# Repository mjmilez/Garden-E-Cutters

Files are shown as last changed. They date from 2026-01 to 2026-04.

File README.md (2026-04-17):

# Garden E-Cutters

## Overview
The Garden E-Cutters shears are a smart harvesting tool that records each cut event along with high-accuracy GPS data. When a cut is detected, the system captures an RTK-corrected GNSS position, logs the event locally, and transmits it to a base station for visualization on a live map dashboard.

## Key Features
- RTK GNSS positioning (u-blox ZED-F9P) for centimeter-level accuracy  
- Hall effect sensor-based cut detection  
- ESP32-based embedded control system  
- Local CSV logging for offline reliability  
- Bluetooth Low Energy (BLE) data transfer to base station  
- Audible and LED feedback for user interaction  
- Debounced trigger logic to prevent duplicate cut events  

## How It Works
1. A cut is detected using a Hall effect sensor on the shears.  
2. The ESP32 captures the next valid GNSS (GNGGA) message from the ZED-F9P.  
3. The event (timestamp + GPS + fix data) is stored locally in a CSV buffer.  
4. When connected, data is transmitted over BLE to the base station.  
5. The base system visualizes cut locations on a map dashboard.

## Hardware
- ESP32 microcontroller  
- u-blox ZED-F9P RTK GNSS receiver  
- Hall effect sensor (cut detection)  
- Piezo buzzer (status feedback)  
- Status LEDs  
- Battery-powered field enclosure  

## Design Focus
- Low-latency cut-to-log workflow  
- Reliable operation under intermittent connectivity  
- Minimal power and compute load on the field device  
- Robust data capture even during GNSS or BLE interruptions  

## Status
Prototype validated in field-like testing with reliable event detection, RTK-level positioning, and stable end-to-end data transfer to the base system.

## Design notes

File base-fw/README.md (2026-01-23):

# Base Firmware

The base firmware runs on an ESP32 (ESP-IDF) and acts as the BLE central for the Garden E-Cutters system. It scans for the shears device, connects when it is found, drives a status LED, and requests log data using the custom log-transfer service.

## What This Firmware Does

### 1. BLE Central for WM-SHEARS
Files: base_ble.c, base_ble.h

The base uses NimBLE in central mode:

- Scans for devices advertising "WM-SHEARS"
- Filters advertisements by name
- Connects automatically when the shears are discovered
- Restarts scanning on disconnect, failed connection attempts, or scan completion
- Reports link state through a callback
- Performs full GATT discovery to locate the log-transfer service and characteristics

### 2. Log Transfer Client
Files: log_transfer_client.c, log_transfer_client.h

The base implements the client side of a simple file transfer protocol:

1. Sends START_TRANSFER with the requested filename
2. Receives STATUS_OK with file size
3. Streams incoming chunks into SPIFFS or a RAM buffer
4. Handles STATUS_TRANSFER_DONE and finalizes storage
5. Dumps the first several lines for debugging

The client is entirely self-contained. BLE only forwards notifications into it.

### 3. Status LED (GPIO 33)
File: base_led.c

LED behavior:
- Blink while scanning or attempting to reconnect
- Solid on when connected

Runs in its own FreeRTOS task.

### 4. SPIFFS Initialization
File: main.c

Mounts the "storage" partition at /spiffs so CSV logs can be written locally.

## Project Structure

```
base-fw/
├── main/
│   ├── main.c
│   ├── base_led.c
│   ├── base_led.h
│   ├── base_ble.c
│   ├── base_ble.h
│   ├── log_transfer_client.c
│   ├── log_transfer_client.h
│   ├── log_transfer_protocol.h
│   ├── log_paths.h
│   └── CMakeLists.txt
└── CMakeLists.txt
```

main.c wires modules together:

- Initialize SPIFFS
- Initialize and start LED system
- Initialize BLE central
- Request logs when connected

## Build and Flash

```
idf.py set-target esp32
idf.py build
idf.py -p <port> flash
idf.py -p <port> monitor
```

Replace <port> with your serial device.

## Hardware Notes

### LED
- GPIO: 33
- Active-high
- Series resistor: 220 to 330 ohms

### BLE Link
- Pairs with the shears advertising as "WM-SHEARS"
- Base works only as central
- Uses NimBLE for low resource usage

## Next Steps

### 1. Per-entry CRC Validation
Future transfers will treat each log entry as a discrete record with:
- entry index
- payload
- CRC

The base will verify each entry before committing it.

### 2. Queue-Based Deletion Pipeline
Once the base receives and validates an entry:
- Write to SPIFFS
- Respond with acknowledgement
- Shears deletes the acknowledged entry
- Shears sends the next entry

This prevents re-sending entire CSV files and provides ordered, reliable delivery.

### 3. Shears-Side Bookkeeping
The shears will maintain:
- A queue of unsent log entries
- A flag for waiting on an acknowledgement
- Logic for deleting entries on acknowledgement
- Ability to resume after disconnects

### 4. Optional Future Telemetry
The base may later subscribe to telemetry characteristics such as:
- force readings
- blade position
- cut events
- GPS triggers
- battery status

### 5. Improved Reconnection Logic
Add backoff or timing control to avoid constant reconnect attempts when the shears are unavailable.

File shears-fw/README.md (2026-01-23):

# Shears Firmware

The shears firmware runs on an ESP32 and provides three core functions for the Garden E-Cutters system:

1. **BLE Peripheral** – advertises as `WM-SHEARS` and exposes the custom log-transfer service.  
2. **GPS Logger** – receives NMEA sentences over UART2, parses `$GPGGA`, and appends rows to a CSV log stored in SPIFFS.  
3. **Status LED** – visually indicates BLE link state.

All continuous work (GPS reads, save requests, BLE I/O, file streaming) runs inside module-specific FreeRTOS tasks. `main.c` simply initializes the modules and ties them together.

---

## Features

### 1. BLE Peripheral (NimBLE)

Implemented in `shears_ble.c`.

- Advertises the name **`WM-SHEARS`**.
- Exposes a custom 16-bit service: **0xFFF0**.
- Provides two characteristics:
  - **Control (0xFFF1)**  
    Accepts `START_TRANSFER` and `ABORT` from the base. Sends STATUS events back.
  - **Data (0xFFF2)**  
    Streams file chunks to the base using notifications.
- Restarts advertising automatically after disconnects.
- Reports connection state to the application via callback (`bleConnChanged` in `main.c`).

---

### 2. Status LED (GPIO 33)

Implemented in `shears_led.c`.

| State | Behavior |
|---|---|
| Advertising / Waiting | Fast blink |
| Connected to Base | Solid on |
| Disconnected / Reconnecting  | Blink |

The LED runs on its own FreeRTOS task and stays independent of BLE and GPS workloads.

---

### 3. GPS Logger (UART2 + SPIFFS + Button)

Implemented in `gps_logger.c`.

Capabilities:

- Reads raw NMEA sentences from a GPS module on **UART2**  
  (RX = GPIO 16, TX = GPIO 17, 9600 baud).
- Reassembles complete NMEA lines in a reader task.
- Tracks the latest full sentence in `latestNmea`.
- Logs `$GPGGA` data into `/spiffs/gps_points.csv`.
- CSV file is automatically created with a header row on first boot.
- Supports two ways to trigger a save:
  - **Physical button** on GPIO 23 (falling-edge interrupt).
  - **Software call:** `gpsLoggerRequestSave()` (used later for BLE-driven saves).

CSV fields:

```
utc_time,latitude,longitude,fix_quality,num_satellites,
hdop,altitude,geoid_height
```

---

## Log Transfer Service (Shears → Base)

Implemented in `log_transfer_server.c`.

- The base requests a file by basename, e.g. `"gps_points.csv"`.
- The shears resolves this to `/spiffs/<name>`.
- The transfer server:
  - validates the request
  - opens the file
  - sends `STATUS_OK` with the size
  - streams indexed data chunks until EOF
  - sends `STATUS_TRANSFER_DONE` when finished
- Chunk order is strictly increasing (`chunkIndex`), enabling the base to detect gaps.

This service is used to offload the GPS log to the base over BLE.

---

## Project Structure

```
shears-fw/
├── main/
│   ├── main.c                 # Top-level wiring
│   ├── shears_led.c/.h        # LED subsystem
│   ├── shears_ble.c/.h        # NimBLE advertising + callbacks
│   ├── gps_logger.c/.h        # UART + SPIFFS + button + CSV logging
│   ├── log_transfer_server.c/.h
│   └── CMakeLists.txt
└── partitions.csv
```

---

## Partition Table

```
nvs,        data, nvs,     0x9000,   0x5000
phy_init,   data, phy,     0xE000,   0x1000
factory,    app,  factory, 0x10000,  0x140000
storage,    data, spiffs,            0x64000
```

SPIFFS is used for the GPS log and any future on-device files.

---

## Build & Flash

Set target:
```
idf.py set-target esp32
```

Build:
```
idf.py build
```

Flash (replace with your serial device):
```
idf.py -p COM5 flash
```

Monitor:
```
idf.py -p COM5 monitor
```

---

## Hardware Notes

### Status LED
- GPIO 33  
- Active-high  
- Series resistor: 220–330 Ω  

### GPS UART (NMEA input)
- RX → GPIO 16  
- TX → GPIO 17  
- 9600 baud  

### Save Button
- GPIO 23  
- Internal pull-up  
- Falling-edge interrupt  

### SPIFFS
- Mounted at `/spiffs`  
- Stores `/spiffs/gps_points.csv`  

---

## Next Steps

- Add CRC to improve file integrity.
- Add a queueing mechanism on the shears to delete log entries once acknowledged by the base.

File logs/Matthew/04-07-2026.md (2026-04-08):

# What I did

- Soldered and configured final project presentation hardware and 3d prints.
- Made sure everything was operable and working.

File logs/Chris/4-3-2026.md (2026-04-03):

## Christian Veltchev - 4/3/2026 Demo Day

**Things Accomplished:** 
- Met with Dr. Sheuller and demoed the end to end functionality
- We were able to 3d print and put all of the technology in some type of encolusre so that it is portable
- Total Working time: 2 hours

**Things to Work on**
- Fix heat shrink on the board

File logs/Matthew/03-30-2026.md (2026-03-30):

# What I did today

- I had to basically restart CAD designs because of SolidWorks errors
- PCB in!!! I soldered componenets to the board. There is media backing this up.

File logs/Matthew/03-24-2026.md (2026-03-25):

# What I did

- I remodeled the enclosure for shears
- Soldered female headers back on the zed f9p board
- Tested to make sure the new header works
- Sent out model to be printed
- did research on how to get ennclosure mounted

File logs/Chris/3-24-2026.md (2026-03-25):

## Christian Veltchev - 3/24/2026 Lab Day

**Things Accomplished:** 
- Added UI support for exporting cuts as CSV (full export and selected-only export).
- Added Deleted tab workflow with recently deleted cuts, 48-hour retention display, and recover-to-active behavior.
- Added select-all behavior for active and deleted tables and fixed tab visibility so deleted content only appears in the Deleted tab.
- Updated frontend API routing logic for Raspberry Pi host/port behavior and validated testing flow expectations.
- Meeting with Alex to discuss release candidate progress and readiness.
- Met with team to discuss possible alterations to the 3D printed enclosure box.
- Total Working time: 5 hours

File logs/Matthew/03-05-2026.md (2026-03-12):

# What I did today 2026-03-05 18:00

- Completely finished the pcb design
  - had to create custom footprints for some things
- Sent a request to lab manager for printing
- Tested the trigger mechanism on shears. Found out that it was longing twice. With that we added debouncing code for the trigger on the shears. It works fine now.
- Tested mobile shears. Works as expected.

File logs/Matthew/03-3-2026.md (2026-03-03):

# What I did today

- I refactored the pcb that connects the esp to the zedf9p.
- Made cardboard prototype of the pcb to see where buttons and switches would sit.
- Did project management with front end team.

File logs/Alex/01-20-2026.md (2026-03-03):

### January 20th – RTK Bring-Up, Verification, and Behavioral Testing

## Goal
Verify that the u-blox LR RTK Base/Rover kit is functioning end-to-end:
- Base broadcasting RTCM corrections
- Rover receiving corrections
- Achieving RTK FIX
- Understanding FIX/FLOAT behavior in real environments
- Identifying which data messages the ESP32 will eventually consume

---

## Base Station Setup
- Powered the **base station** via USB
- Connected:
  - GNSS antenna to ZED-F9P
  - LR antenna to XBee-SX radio
- Left base **stationary** for the duration of testing
- Observed LEDs:
  - PWR LED solid
  - PVT LED blinking (GNSS navigation active)
  - GPS → XBee LED blinking (data flowing to radio)

**Conclusion:**  
Base hardware, power, and GNSS reception were all healthy.

---

## Rover Setup
- Powered the **rover** via GPS-side USB
- Connected to u-center through the ZED-F9P USB (not XBee USB)
- Verified rover antenna orientation and open sky exposure
- Confirmed rover initially reported:
  - `3D / DGNSS / FLOAT`

**Conclusion:**  
Rover was receiving differential corrections and participating in RTK.

---

## RTCM Verification
- Opened `UBX → RXM → RTCM` in u-center
- Observed RTCM messages incrementing
- In `UBX → NAV → PVT`, observed:
  - `Fix Flags: FixOK DGNSS`
  - `Age of most recently received differential corrections: 1–2 s`

**Conclusion:**  
RTCM corrections were being successfully transmitted from base to rover via XBee.

---

## Achieving RTK FIX
- Initially remained in `FLOAT` due to partial tree cover
- Moved **only the rover** to clearer sky while leaving base fixed
- After remaining stationary:
  - Fix mode transitioned to `3D / DGNSS / FIXED`
  - 2D accuracy ≈ **1 cm**
  - 3D accuracy ≈ **2–3 cm**

**Conclusion:**  
The full RTK pipeline (base → radio → rover → ambiguity resolution) works.

---

## Environmental & Behavioral Testing
- Moved rover under tree canopy and a ceiling
- Observed:
  - FIX → FLOAT transitions
  - Accuracy fields remained low for a short time (filter inertia)
- Learned:
  - Accuracy values can look “good” even when FIX is lost
  - FIX state is about **carrier phase confidence**, not raw accuracy
- After environmental degradation:
  - FIX recovery took ~30 minutes of uninterrupted clean sky

**Conclusion:**  
RTK FIX recovery time is environment-dependent and non-deterministic.

---

## u-center Message Inspection (ESP32-Relevant)
- `NAV-HPPOSLLH` **not populated** (not enabled by default)
- `NAV-PVT` **fully populated and active**
  - Provides:
    - Latitude / Longitude
    - Fix type
    - Carrier range status
    - DGNSS state
    - Satellite count
    - PDOP

**Conclusion:**  
ESP32 integration can start using **UBX NAV-PVT** without changing configuration.

---

## Key Technical Takeaways
- RTK FIX is not guaranteed at all times
- FLOAT/DGNSS can appear very accurate but is not integer-resolved
- FIX must be explicitly gated at log time
- Base placement and sky view dominate system behavior
- HPPOSLLH is optional and can be enabled later

---

## Implications for Final Design
For “log a watermelon cut” functionality:
- On button press:
  - Only log if fix state is **FIXED**
  - Otherwise wait or reject
- Always log fix type alongside coordinates
- ESP32 will parse:
  - `UBX NAV-PVT`
  - Not NMEA
- Averaging multiple samples after FIX is recommended

---

## Current Status
- ✅ Base working
- ✅ Rover working
- ✅ RTCM corrections verified
- ✅ RTK FIX achieved
- ✅ FIX/FLOAT behavior understood
- 🔜 ESP32 UART parsing and button-press logic

---

## Open Next Steps
- Define ESP32 UART wiring and voltage levels
- Implement UBX NAV-PVT parser on ESP32
- Add button-press state machine:
  - Wait for FIX
  - Sample N points
  - Average and store
- Optional: enable NAV-HPPOSLLH for higher-precision logging

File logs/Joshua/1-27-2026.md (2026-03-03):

## Joshua Arroyo - 1/27/2026 Lab Day

- Debugged UART connection between GPS module and shears ESP32  
- Fixed NMEA reception issues by setting a common baud rate  
- Improved CSV print function to efficiently inspect recent GPS data during debugging  

**Next step:**  
- Update save task to wait for a `$GNGGA` UART sentence before attempting a save, removing the need for repeated save triggers

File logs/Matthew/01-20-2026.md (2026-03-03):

#What I did today

- github alpha sprint planning done. Specifying roles and details.

- brainstorming ideas for the design for the shears.
  - Ideas:
    - antenna has to be in specific location
    - Has to be portable
    - Has good signal

- Mockup design created for the physical shears
- Looked at bought shears that we should be able to take apart.

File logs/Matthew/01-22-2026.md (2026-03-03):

# What I did 2026-01-22T10:45:51

- trying to figure out how the triggering system works
  - https://www.youtube.com/watch?v=w-at7JCzWaQ

[x] Dismantling 
    [x] shear battery 
    [x] body to see internals for triggering

[x] Discussed how we would mount the zed-f9p and esp

- determined that we log location along with accuracy. Basically, all the data.

- determined that a cutter would wear:
  - the radio
  - all hardware (zed-f9p,esp32)

- Went through this tutorial to install U center on mac
 - https://www.ardusimple.com/how-to-install-u-center-on-macos-and-connect-gnss-receiver-to-it/

- Read documentation on u-center and zed-f9p

- realized i have a dual boot computer ...

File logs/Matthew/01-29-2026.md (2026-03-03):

# What I did 2026-01-29 14:43

- Got the dev environment working again on my computer
- Created clear functionality on holding button for two seconds
- I also noticed a bug where sometimes when you press the button it would not log the time.
- Based on this I decided to look over the code and found that we are just hoping the gga sentence is after the button press. This was causing the bug.
- I decided to write functionality to arm for the next GGA sentence coming. This made sure that a location is always logged no matter what. We are not moving at super high speeds so this waiting for the next sentence is not critical.

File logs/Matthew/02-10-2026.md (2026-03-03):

# What I did today

## Actions
- I breadboarded everything that would be in the shear box on one bread board.
- I added peripherals: 4 buttons (1 prime button, and 3 gps logging buttons), 1 LED for showing logging state, and a piezo for sound feedback.
- programmed pwm on gpio pins for piezo to make it louder.
- Fixed clear csv logic because it was not working sometimes.

## Research
- I looked into designs for encapsulating hardware.
- Thought about pcb designs for connecting the shears to the zed.

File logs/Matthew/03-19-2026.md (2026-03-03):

# What I did today

- I changed the code and the wiring for the spdt switch
- picture is in /Media !

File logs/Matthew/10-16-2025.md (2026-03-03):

# Findings
- I looked up how to interface the gps rtk with an ESP32.
- The connection should be seemless using a comm protocal like i2C or UART

- I also overall just looked up how ESPs worked and how to make an environment

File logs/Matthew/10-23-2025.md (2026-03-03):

## created accuracy to cost ratio
- This was to determine how we which option we would finally chose

Field small/medium (so UWB anchor network ≈ 8 anchors).

Anchor module price ≈ $70 each (mid-range).

UWB tag ≈ $50.

RTK rover (per-shear) ≈ $300 (NEO-F9P / u-blox class).

RTK base station ≈ $400 (mid-range; could be $250–$750).

Basic GNSS (consumer) module ≈ $30 (phone-style GNSS).

DGPS/SBAS-capable receiver ≈ $100 (board that uses WAAS/EGNOS corrections).

IMU ≈ $25 (BNO085 / similar).

Small field server / gateway ≈ $200 (Pi + LTE / router).

Accuracy numbers are typical real-world expectations:

GPS (consumer): ~5 m (median; 3–10 m typical)

DGPS/SBAS: ~0.3–1.0 m (use 0.5 m)

UWB (well deployed): ~0.10–0.30 m (use 0.15 m)

RTK GNSS: ~0.01–0.03 m (use 0.02 m = 2 cm)

Hybrid (RTK+UWB fused): uses RTK where available (2 cm) and UWB for GNSS outages — main benefit is robustness, not smaller nominal error than RTK.

- Locationing was based on Schueller specifications.

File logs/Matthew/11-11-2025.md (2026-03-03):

## What I did

- setup dev environment for esp32.

- I tested the dev environment with the ESP that I have with blink example, etc.

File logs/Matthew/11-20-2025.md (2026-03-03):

# What I did

- Integrated all components of the prototype for presentation.

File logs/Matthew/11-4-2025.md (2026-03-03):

## What I did

- Researched the data format of the zed-f9p chip
- Through the research, I realized that there is a design decision in this. There are different forms of gps data formats such as UBX, NMEA, etc.

- Moreover, I realized how that data would be sent in terms of hardware. Thinking we use i2C

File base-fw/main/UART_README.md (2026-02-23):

# UART Protocol (Base ESP32 → Raspberry Pi)

Baud: 115200\

Wiring: ESP32 TX → Pi RX\
ESP32 RX ← Pi TX\
GND ↔ GND

------------------------------------------------------------------------

## Packet Layout

Every packet:

\[0xAA\]\[TYPE\]\[LEN\]\[PAYLOAD...\]\[CHECKSUM\]

START byte = 0xAA

LEN = 1 byte (0--255)

CHECKSUM = XOR of: TYPE \^ LEN \^ all payload bytes

START is NOT included in checksum.

------------------------------------------------------------------------

## Packet Types

0x01 = START\
0x02 = DATA\
0x03 = END\
0x04 = ACK\
0x05 = COMMIT

------------------------------------------------------------------------

## START

Payload: \[fileSize uint32 little-endian\]

Pi must ACK.

------------------------------------------------------------------------

## DATA

Payload: \[file bytes\]

Max 255 bytes per packet.

Each DATA must be ACKed before next is sent.

------------------------------------------------------------------------

## END

No payload.

Pi ACKs it.

------------------------------------------------------------------------

## COMMIT

Payload: \[status\]

0x00 = success\
Anything else = failure

ESP32 only clears the file after COMMIT(0x00).

------------------------------------------------------------------------

Flow:

ESP → START\
Pi → ACK\
ESP → DATA\
Pi → ACK\
(repeat)\
ESP → END\
Pi → ACK\
Pi verifies file\
Pi → COMMIT\
ESP clears file

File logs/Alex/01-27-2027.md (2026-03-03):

### January 27th – Team Meeting and Data Integration Discussion

## Summary
- Showed up late
- Installed Cursor
- Discussed data integration with group members
- Team meeting with Dr. Sheuller (2 hours)

---

## Activities

### Morning
- Arrived late to work
- Installed Cursor development environment

### Data Integration Discussion
- Talked with group members regarding data integration
- Discussed approach and requirements for the project

### Team Meeting
- Met with Dr. Sheuller
- Duration: 2 hours
- Topics covered: [Add details as needed]

---

## Current Status
- ✅ Cursor installed
- ✅ Data integration discussion completed
- ✅ Team meeting with Dr. Sheuller completed

---

## Next Steps
- [Add follow-up items from meeting]

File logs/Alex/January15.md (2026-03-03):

### January 15th
Setting it up
* labeled "rover" and "base" at the bottom of the board. 
* added a sticker on the chip that we are not going to move that labels rover for easier visibility

Going through the User Guide for the XLR kit.

## setting up the base station
there was a youtube video explaining how so iteratively hooked up the radio and lr antenna to base station and rover

## setting up Ucenter 
* had to get the proper 2013 Visual Code from microsoft architecture to get UCenter to run on my computer

## going outside
* Matthew and I set up the rover and base station and went out in front of the REITZ to get sattelite exposure and test the accuracy
*WE RAN INTO PROBLEMS*
* one, the data type never changed from 3D on the rover. While its devent location accuracy it did not meet the parameters of what we need for the assignment. 
* We were unable to ascertain wether or not the base and reciever have established a connection
* gained some familiarity with the UCenter Platform
* determined that at least partially the base has been configured to be the base station and the rover to be the rover, their transmittions line up with such

## current unfinished problems
* the rover never recieved RTCM messages (the correction messages neccessary for accuracy and the point of RTK)
* the base after 90 seconds stop setting its position this meant the average location for the base never got down to centimeter level (only got to 2.11 meters) that it needs to function properly. 
* why is the base not working? , some say that it takes 30 minutes to fully find the bases fixed location but our base stopped even calculating it's location after 90 seconds. 
* is the problem with the rover that the base doesn't have it's location fixed?

## long term problem
* need to figure out how to configure the rover correctly to send the messages to the ESP32 for its location

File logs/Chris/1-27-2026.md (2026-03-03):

## Christian Veltchev - 1/27/2026 Lab Day

**Things Accomplished:** 
- Discussed with Matthew about the different limitations regarding Mapping Interfaces/programs that are able to be used or installed onto the ESP32
- Meeting with Dr. Sheuller to update him and answer any questions regarding the Alpha Build coming up
- Total Working time: 4 hours

**Next step(s):**  
- Looked into ArcGIS shich could serve a means to an end regarding mapping the coordinates to a map on the web user interface

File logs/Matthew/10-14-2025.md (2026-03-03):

# 10-14-2025

## Researching tradeoffs between each geolocationing
### Table given from chatGpt to summarize findings
| System | Typical accuracy | Cost & complexity | Works in blocked LOS? | Good fit for your project? |
| --- | ---: | --- | ---: | --- |
| **Standard GPS (single-freq)** | 3–10 m | Low cost, low complexity | Yes (satellite) | No — too coarse |
| **DGPS / SBAS (WAAS)** | 0.3–1 m | Moderate | Yes, depends on correction availability | Possibly — borderline for 0.3–0.5 m |
| **RTK (GNSS RTK)** | 0.01–0.03 m (1–3 cm) | Higher cost, needs base & comms | Needs good sky view | Excellent but more expensive |
| **Local radio triangulation (RSSI)** | ~2–20 m (highly variable) | Low–moderate | Works indoors/blocked | Not suitable alone |
| **Local tower TDoA/AoA (general-purpose LPS)** | 0.5–2+ m (depends on tech) | Moderate-high, needs infrastructure | Can work with LOS or partial LOS | Maybe — if carefully designed |
| **UWB anchor network (local beacons)** | 0.05–0.30 m (5–30 cm) | Moderate, simple anchors | Best with LOS but robust in fields | Very good — meets your goal |
| **Hybrid: RTK + local anchors + IMU fusion** | cm–submeter depending on mode | Highest complexity | Robust | Best overall reliability |

- UWB seems like a solid option to lower costs. We are considering this as an option.

- I think prices would be similar to RTK.

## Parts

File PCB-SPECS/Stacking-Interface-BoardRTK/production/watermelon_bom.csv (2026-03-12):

Designator | Footprint | Quantity | Value | LCSC Part #
BUTTON1, BUTTON2 | SW_PUSH_6mm | 2 | SW_Push
BZ1 | Buzzer_D14mm_H7mm_P10mm | 1 | Buzzer
D1 | LED_D1.8mm_W1.8mm_H2.4mm_Horizontal_O1.27mm_Z1.6mm | 1 | Blue
D2 | LED_D1.8mm_W1.8mm_H2.4mm_Horizontal_O1.27mm_Z1.6mm | 1 | Green(Status)
ESP_LEFT1, ESP_RIGHT1 | PinSocket_1x15_P2.54mm_Vertical | 2 | Conn_01x15_Socket
J1 | TerminalBlock_Altech_AK300-2_P5.00mm | 1 | Screw_Terminal_01x02
PRIME_SWITCH1 | spdt_switch | 1 | SW_SPDT
R1, R2 | R_Axial_DIN0207_L6.3mm_D2.5mm_P10.16mm_Horizontal | 2 | 1k
RTK_BOTTOM_LEFT1 | PinHeader_1x10_P2.54mm_Vertical | 1 | Conn_01x10_Pin
RTK_BOTTOM_RIGHT1, RTK_TOP_LEFT1 | PinHeader_1x08_P2.54mm_Vertical | 2 | Conn_01x08_Pin
RTK_TOP_RIGHT1 | PinHeader_1x06_P2.54mm_Vertical | 1 | Conn_01x06_Pin

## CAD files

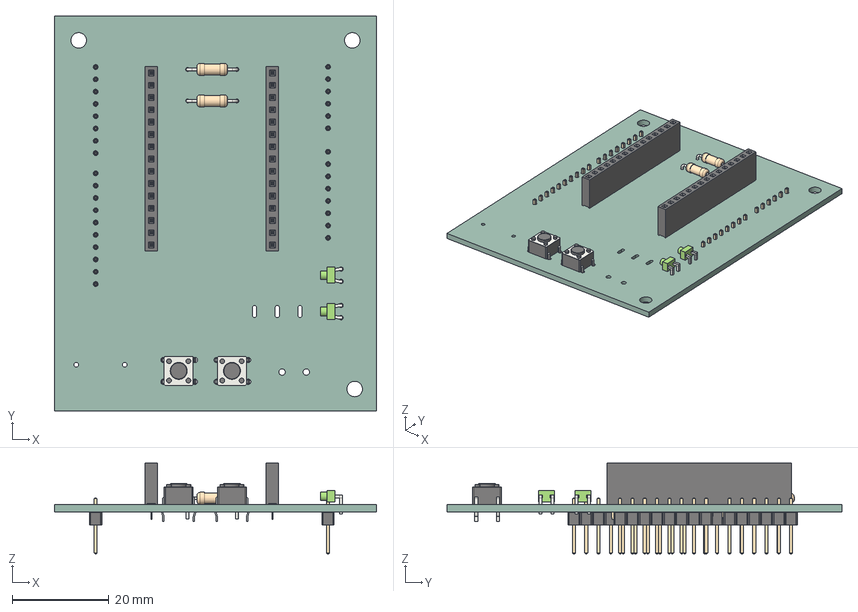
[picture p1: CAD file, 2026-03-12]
PCB-SPECS/Stacking-Interface-BoardRTK/output_files/cad/pcb.step
66.5 x 81.5 x 18.7 mm
PinSocket_1x15_P2.54mm_Vertical x 2
LED_D1.8mm_W1.8mm_H2.4mm_Horizontal_O1.27mm_Z1.6mm x 2
SW_PUSH_6mm x 2
R_Axial_DIN0207_L6.3mm_D2.5mm_P10.16mm_Horizontal x 2
PinHeader_1x10_P2.54mm_Vertical
PinHeader_1x06_P2.54mm_Vertical
PinHeader_1x08_P2.54mm_Vertical x 2
Stacking-Interface-BoardRTK_PCB

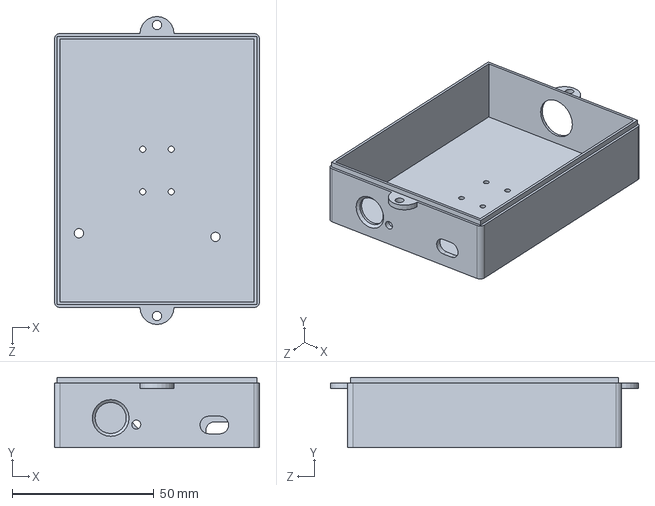
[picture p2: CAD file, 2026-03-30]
SolidWorks/base/box.SLDPRT
72.5 x 24.8 x 108.8 mm

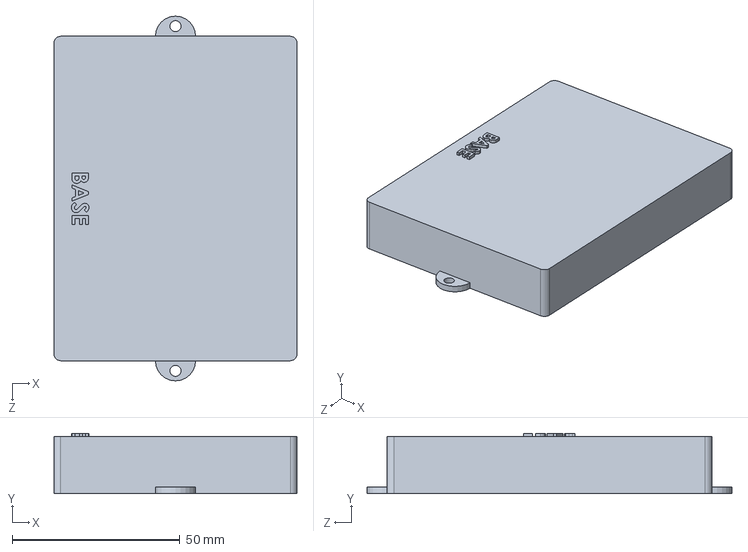
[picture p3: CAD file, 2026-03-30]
SolidWorks/base/lid.SLDPRT
72.5 x 18.0 x 108.8 mm

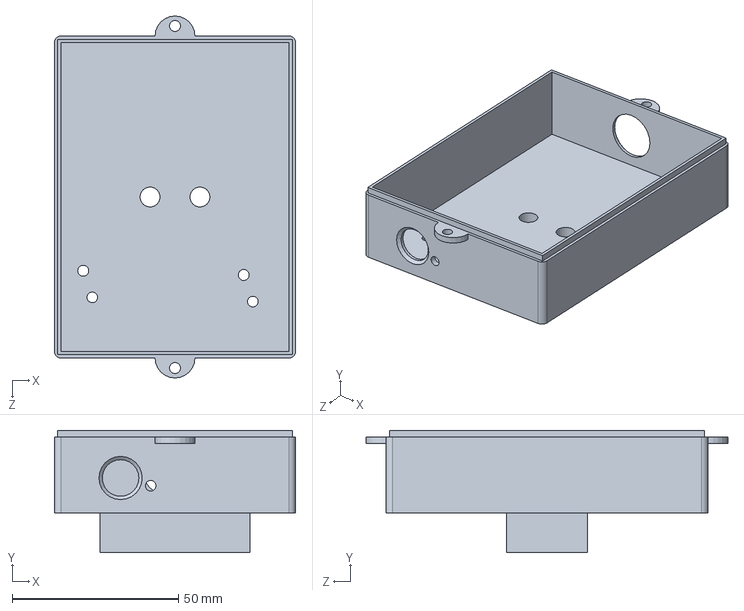
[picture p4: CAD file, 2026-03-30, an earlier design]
SolidWorks/rover/box.SLDPRT
72.5 x 36.8 x 108.8 mm

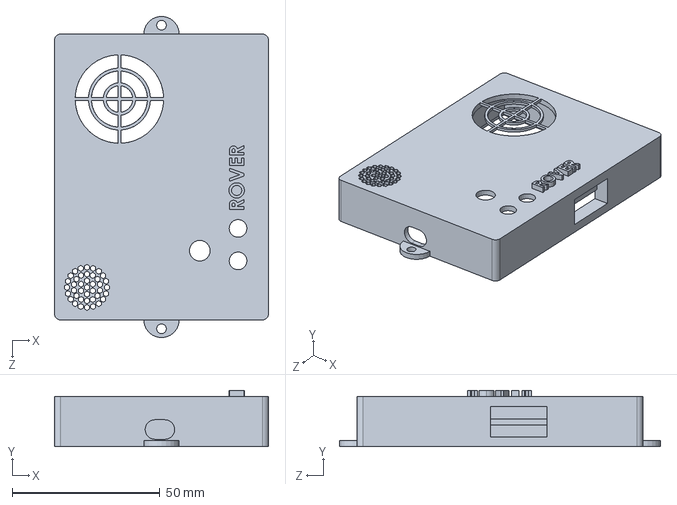
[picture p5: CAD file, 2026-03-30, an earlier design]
SolidWorks/rover/lid.SLDPRT
72.5 x 19.0 x 108.8 mm

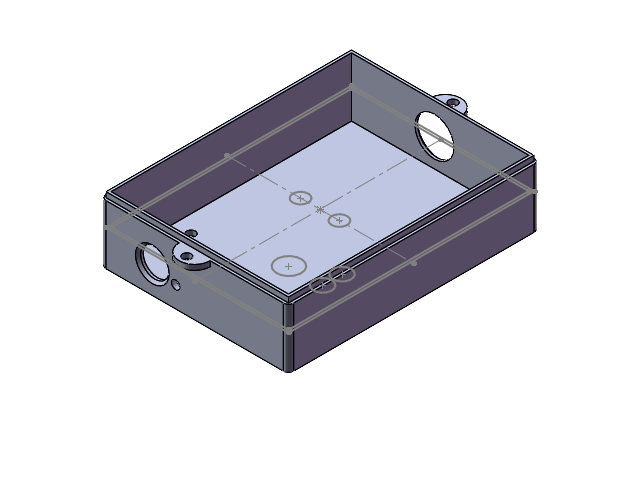
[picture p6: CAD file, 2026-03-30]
SolidWorks/base/base.SLDASM
gopro_fng_v3

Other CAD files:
SolidWorks/base/box.STL
SolidWorks/base/lid.STL
SolidWorks/rover/box.STL
SolidWorks/rover/lid.STL

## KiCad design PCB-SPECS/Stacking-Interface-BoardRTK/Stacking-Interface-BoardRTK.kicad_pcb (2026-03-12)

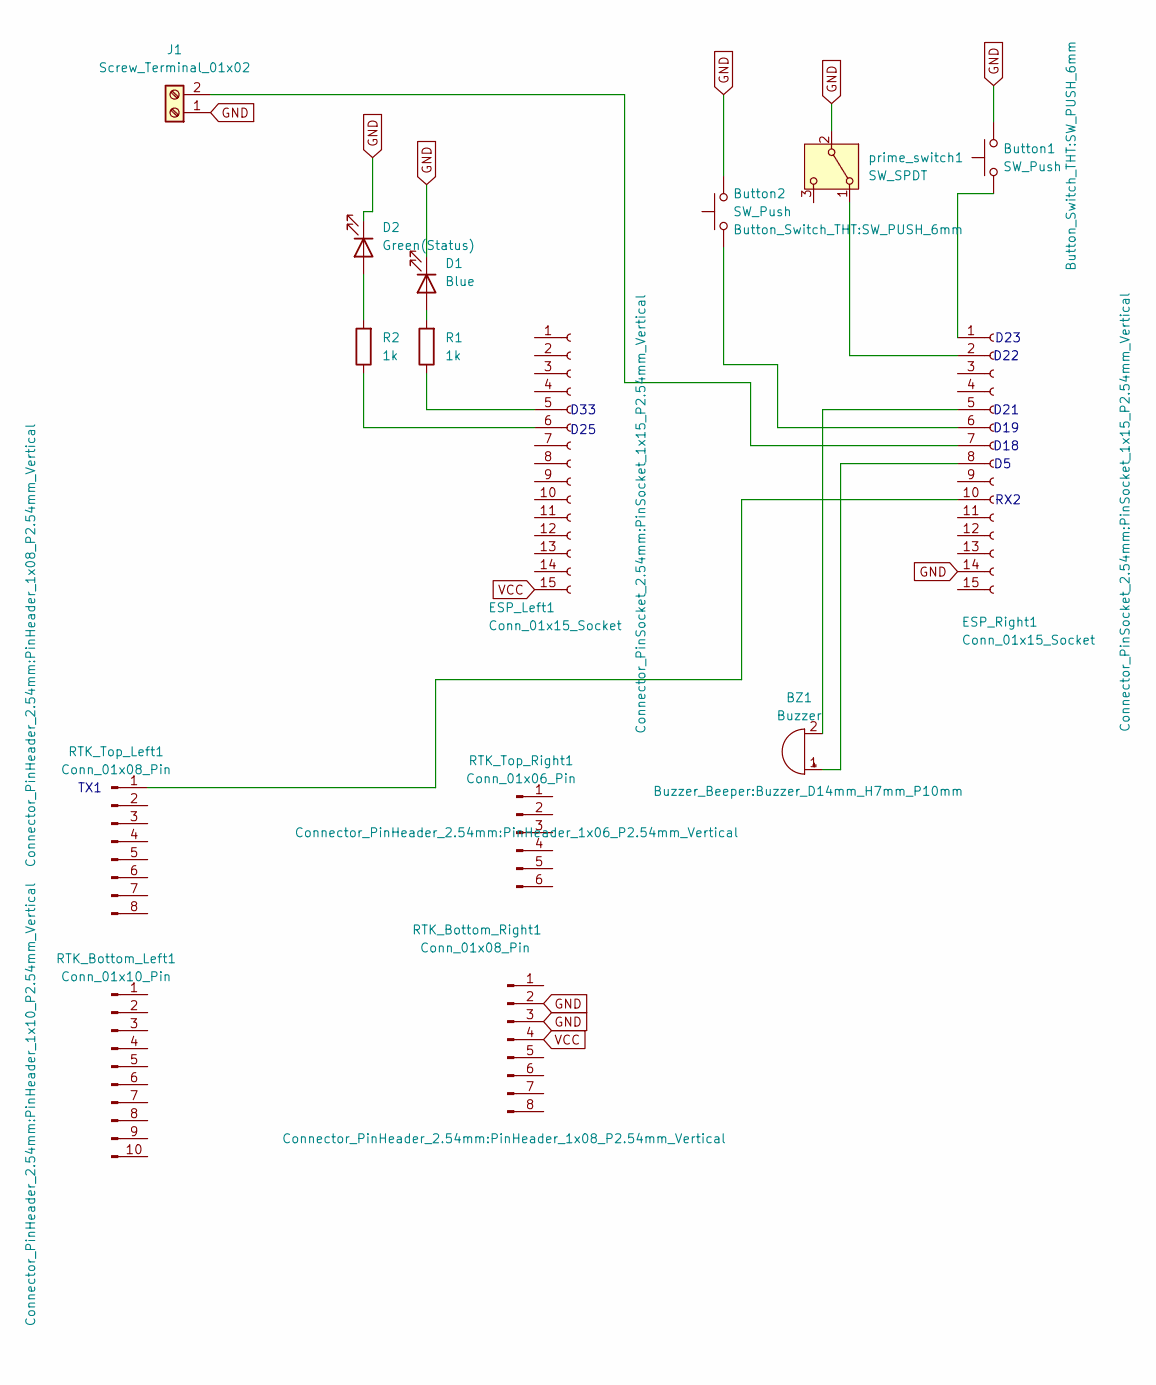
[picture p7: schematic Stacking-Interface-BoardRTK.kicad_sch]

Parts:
BZ1: Buzzer; Buzzer_D14mm_H7mm_P10mm
Button1, Button2: SW_Push; SW_PUSH_6mm
D1: Blue; LED_D1.8mm_W1.8mm_H2.4mm_Horizontal_O1.27mm_Z1.6mm
D2: Green(Status); LED_D1.8mm_W1.8mm_H2.4mm_Horizontal_O1.27mm_Z1.6mm
ESP_Left1: Conn_01x15_Socket; PinSocket_1x15_P2.54mm_Vertical
ESP_Right1: Conn_01x15_Socket; PinSocket_1x15_P2.54mm_Vertical
J1: Screw_Terminal_01x02; TerminalBlock_Altech_AK300-2_P5.00mm
R1, R2: 1k; R_Axial_DIN0207_L6.3mm_D2.5mm_P10.16mm_Horizontal
RTK_Bottom_Left1: Conn_01x10_Pin; PinHeader_1x10_P2.54mm_Vertical
RTK_Bottom_Right1: Conn_01x08_Pin; PinHeader_1x08_P2.54mm_Vertical
RTK_Top_Left1: Conn_01x08_Pin; PinHeader_1x08_P2.54mm_Vertical
RTK_Top_Right1: Conn_01x06_Pin; PinHeader_1x06_P2.54mm_Vertical
prime_switch1: SW_SPDT; spdt_switch

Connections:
GND: Button1.2, Button2.2, D1.1 (K), D2.1 (K), ESP_Right1.14, J1.1, RTK_Bottom_Right1.2, RTK_Bottom_Right1.3, prime_switch1.2 (B)
unnamed: BZ1.1 (+), ESP_Right1.8
unnamed: BZ1.2 (-), ESP_Right1.5
unnamed: D1.2 (A), R1.2
unnamed: D2.2 (A), R2.2
unnamed: ESP_Left1.5, R1.1
unnamed: ESP_Left1.6, R2.1
unnamed: Button1.1, ESP_Right1.1
unnamed: ESP_Right1.2, prime_switch1.1 (A)
unnamed: Button2.1, ESP_Right1.6
unnamed: ESP_Right1.7, J1.2
unnamed: ESP_Right1.10, RTK_Top_Left1.1 (TX1)
VCC: ESP_Left1.15, RTK_Bottom_Right1.4

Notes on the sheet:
D33
D21
D23
D22
RX2
D25
D19
TX1
D18

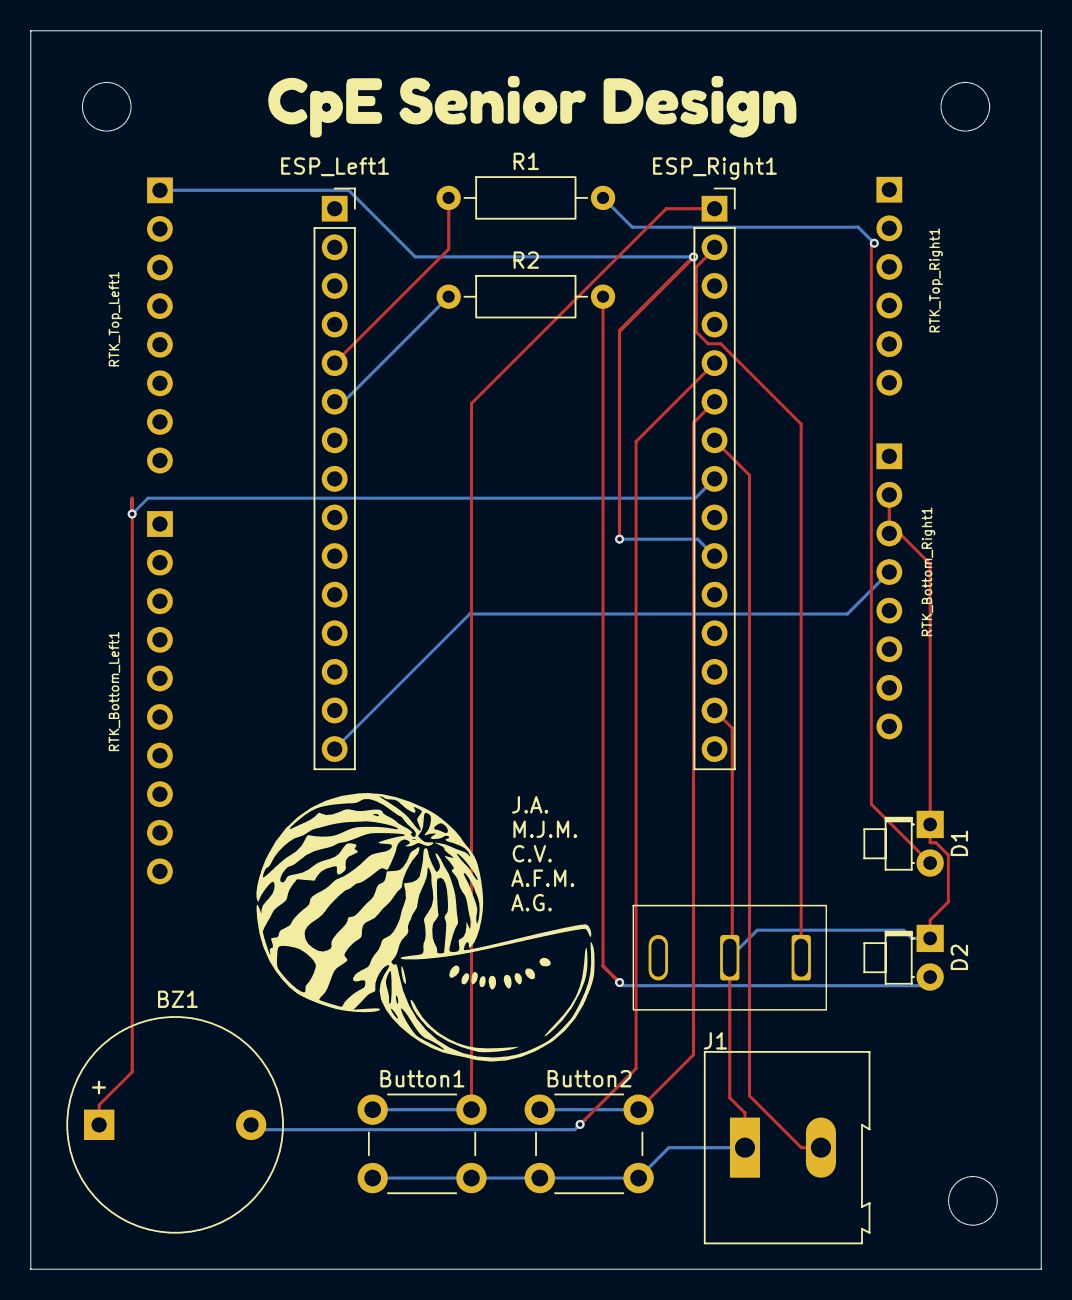
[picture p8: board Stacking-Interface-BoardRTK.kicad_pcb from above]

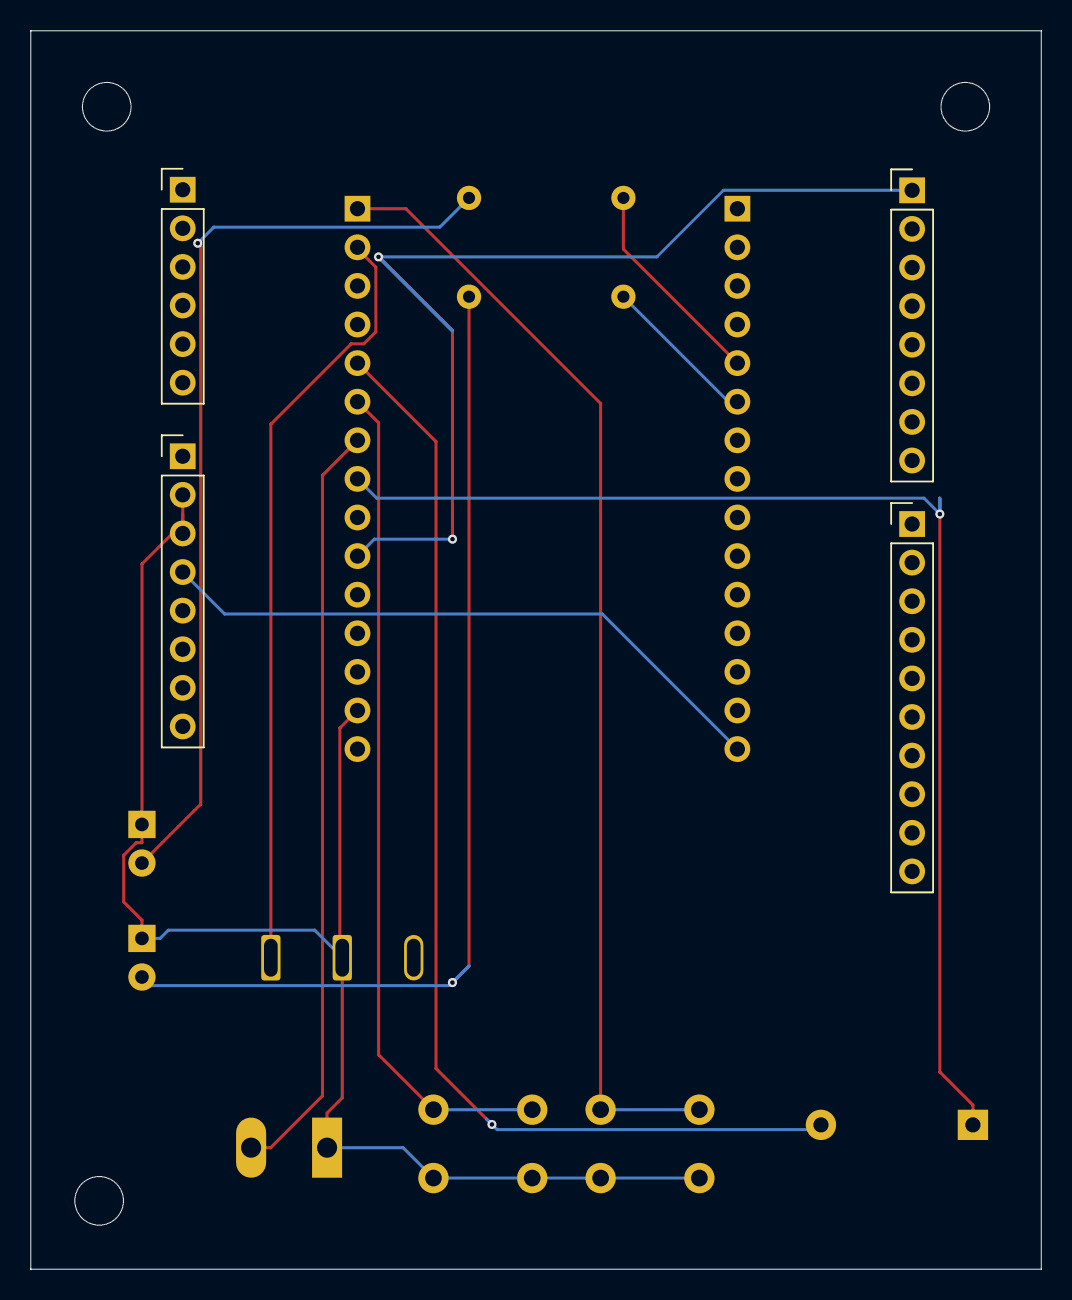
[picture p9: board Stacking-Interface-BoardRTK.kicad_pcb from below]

Board: 2 copper layers, 66.5 x 81.5 mm, 19 parts (4 on the bottom side), 13 nets.

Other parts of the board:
hole1, hole2, hole3: MountingHole_3.2mm_M3
kibuzzard-69A9F479: G***; kibuzzard-69A9F479

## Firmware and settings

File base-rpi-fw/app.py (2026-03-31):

"""
app.py

Watermelon Hub — Raspberry Pi web server.

Endpoints:
    GET  /                      Serve Chris's frontend (static/index.html)
    GET  /api/points            All GPS points as JSON
    GET  /api/latest            Latest N points (default 50)
    GET  /api/status            Transfer state + point count
    GET  /api/export            Download all points as CSV
    POST /api/points/delete     Soft-delete points by ID list
    POST /api/points/restore    Restore soft-deleted points by ID list
    GET  /api/points/deleted    List of soft-deleted points (trash)
    POST /api/clear             Delete all points (testing only)
    POST /api/cuts              Dev endpoint for inserting cuts
    
Background tasks:
    - UART receiver thread: Listens for incoming CSV data from ESP32, parses it, and stores in SQLite.
    - Purge thread: Periodically deletes points older than a certain age (48 hours) to prevent unbounded growth.

The UART receiver runs in a background daemon thread, listening for
file transfers from the ESP32. Received CSV data is parsed and stored
in SQLite. Flask reads from the same database.
"""

import argparse
import io
import csv
import logging
import threading
import time

from flask import Flask, jsonify, Response, request

import config
import database
import uart_receiver

logging.basicConfig(
    level=logging.INFO,
    format="%(asctime)s [%(name)s] %(levelname)s: %(message)s",
)
log = logging.getLogger("app")

app = Flask(__name__, static_folder="static", static_url_path="")

# ── Background purge thread ────────────────────────────────────────

PURGE_INTERVAL_SECONDS = 3600   # Run purge every hour
PURGE_AFTER_HOURS = 48          # Purge points older than this (48 hours)

def _purge_loop():
    """Periodically purge expired soft-deleted points."""
    while True:
        time.sleep(PURGE_INTERVAL_SECONDS)
        try:
            purged = database.purge_expired_deleted(hours=PURGE_AFTER_HOURS)
            if purged > 0:
                log.info("Purge cycle: removed %d expired point(s)", purged)
        except Exception as e:
            log.error("Purge cycle error: %s", e)


def start_purge_thread():
    """Launch the background purge thread as a daemon."""
    thread = threading.Thread(
        target=_purge_loop,
        daemon=True,
        name="purge-expired",
    )
    thread.start()
    log.info("Purge thread started (every %ds, threshold %dh)",
             PURGE_INTERVAL_SECONDS, PURGE_AFTER_HOURS)
    

# ── Routes ─────────────────────────────────────────────────────────

@app.route("/tiles/<int:z>/<int:x>/<int:y>.png")
def serve_tile(z, x, y):
    """Serve offline map tiles from the MBTiles file."""
    import sqlite3 as _sqlite3
    tms_y = (2 ** z) - 1 - y
    try:
        conn = _sqlite3.connect("uf_campus.mbtiles")
        cursor = conn.cursor()
        cursor.execute(
            "SELECT tile_data FROM tiles WHERE zoom_level=? AND tile_column=? AND tile_row=?",
            (z, x, tms_y),
        )
        row = cursor.fetchone()
        conn.close()
        if row:
            return Response(row[0], mimetype="image/png")
        return Response(status=404)
    except Exception:
        return Response(status=404)

@app.route("/")
def index():
    return app.send_static_file("index.html")


@app.route("/api/points", methods=["GET"])
def api_points():
    """All GPS points, oldest first."""
    points = database.get_all_points()
    return jsonify(points)


@app.route("/api/latest", methods=["GET"])
def api_latest():
    """Latest N points (default 50). Pass ?n=100 to change."""
    n = request.args.get("n", 50, type=int)
    points = database.get_latest_points(n)
    return jsonify(points)


@app.route("/api/status", methods=["GET"])
def api_status():
    """Transfer state and total point count."""
    status = uart_receiver.get_status()
    status["total_points"] = database.get_point_count()
    return jsonify(status)


@app.route("/api/export", methods=["GET"])
def api_export():
    """Download all active GPS points as a CSV file."""
    points = database.get_all_points()

    output = io.StringIO()
    writer = csv.writer(output)
    writer.writerow([
        "id", "utc_date", "utc_time", "latitude", "longitude",
        "fix_quality", "num_satellites", "hdop",
        "altitude", "geoid_height",
    ])
    for p in points:
        writer.writerow([
            p["id"], p["utc_date"], p["utc_time"], p["latitude"], p["longitude"],
            p["fix_quality"], p["num_satellites"], p["hdop"],
            p["altitude"], p["geoid_height"],
        ])

    return Response(
        output.getvalue(),
        mimetype="text/csv",
        headers={"Content-Disposition": "attachment; filename=gps_export.csv"},
    )

@app.route("/api/points/delete", methods=["POST"])
def api_delete_points():
    """
    Soft-delete one or more points.
    
    Request body (JSON):
    { "ids": [1, 3, 5]  # List of point IDs to soft-delete}
    
    Response:
    { "status": "ok", "deleted": "3" }
    """
    data = request.get_json(silent=True)
    if not data or "ids" not in data:
        return jsonify({"status": "error", "message": "Missing 'ids' in request body"}), 400
    
    ids = data["ids"]
    if not isinstance(ids, list) or not all(isinstance(i, int) for i in ids):
        return jsonify({"status": "error", "message": "'ids' must be a list of integers"}), 400
    
    if len(ids) == 0:
        return jsonify({"status": "ok", "deleted": "0"})
    
    affected = database.soft_delete_points(ids)
    return jsonify({"status": "ok", "deleted": affected})

@app.route("/api/points/restore", methods=["POST"])
def api_restore_points():
    """
    Restore one or more soft-deleted points.
    
    Request body (JSON):
    { "ids": [1, 3, 5]  # List of point IDs to restore}
    
    Response:
    { "status": "ok", "restored": "3" }
    """
    data = request.get_json(silent=True)
    if not data or "ids" not in data:
        return jsonify({"status": "error", "message": "Missing 'ids' in request body"}), 400
    
    ids = data["ids"]
    if not isinstance(ids, list) or not all(isinstance(i, int) for i in ids):
        return jsonify({"status": "error", "message": "'ids' must be a list of integers"}), 400
    
    if len(ids) == 0:
        return jsonify({"status": "ok", "restored": "0"})
    
    affected = database.restore_points(ids)
    return jsonify({"status": "ok", "restored": affected})

@app.route("/api/points/deleted", methods=["GET"])
def api_deleted_points():
    """
    List of soft-deleted points (the "trash").
    
    Response includes the deleted_at timestamp 
    to help identify old points that may need purging.
    """
    deleted = database.get_deleted_points()
    return jsonify(deleted)

@app.route("/api/clear", methods=["POST"])
def api_clear():
    """Clear all GPS points. For testing only."""
    database.clear_all_points()
    return jsonify({"status": "ok", "message": "All points cleared"})


# ── Backwards-compatible aliases for Chris's existing frontend ─────
# His app.js might still poll /api/cuts — these map to the same data.

@app.route("/api/cuts", methods=["GET", "POST"])
def api_cuts_compat():
    if request.method == "POST":
        data = request.get_json()
        if not data:
            return jsonify({"error": "No JSON body provided"}), 400

        lat = data.get('lat')
        lng = data.get('lng')
        timestamp = data.get('timestamp')
        hdop = data.get('hdop')
        fix_quality = data.get('fix_quality')
        utc_date = data.get('date')

        if lat is None or lng is None:
            return jsonify({"error": "lat and lng are required"}), 400

        try:
            new_id = database.insert_cut(
                float(lat),
                float(lng),
                timestamp,
                float(hdop) if hdop is not None else None,
                utc_date,
                int(fix_quality) if fix_quality is not None else None,
            )
            return jsonify({"success": True, "id": new_id}), 201
        except Exception as e:
            return jsonify({"error": str(e)}), 500

    # GET
    return api_points()


# ── Entry point ────────────────────────────────────────────────────

def main():
    parser = argparse.ArgumentParser(description="Watermelon Hub Pi Server")
    parser.add_argument("--port", type=int, default=config.WEB_PORT,
                        help="Web server port (default: %d)" % config.WEB_PORT)
    parser.add_argument("--serial", type=str, default=config.SERIAL_PORT,
                        help="Serial port (default: %s)" % config.SERIAL_PORT)
    parser.add_argument("--baud", type=int, default=config.SERIAL_BAUD,
                        help="Baud rate (default: %d)" % config.SERIAL_BAUD)
    parser.add_argument("--no-serial", action="store_true",
                        help="Skip UART receiver (for testing without ESP32)")
    args = parser.parse_args()

    database.init_db()

    if not args.no_serial:
        uart_receiver.start(port=args.serial, baud=args.baud)
    else:
        log.info("UART receiver disabled (--no-serial mode)")
        
    start_purge_thread()

    log.info("Starting web server on %s:%d", config.WEB_HOST, args.port)
    app.run(host=config.WEB_HOST, port=args.port, debug=False)


if __name__ == "__main__":
    main()

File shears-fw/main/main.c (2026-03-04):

/*
 * main.c
 *
 * Top-level entry point for the shears firmware.
 *
 * Startup sequence:
 *   - initialize the status LED subsystem
 *   - start the GPS logger (SPIFFS, UART, button ISR, background tasks)
 *   - start BLE in peripheral mode and advertise as "WM-SHEARS"
 *
 * Ongoing work (GPS reads, save requests, BLE activity, log transfers)
 * runs inside module-specific FreeRTOS tasks.
 */

#include "shears_led.h"
#include "shears_ble.h"
#include "shears_spiffs.h"
#include "gps_logger.h"

/* --- BLE connection state ------------------------------------------------- */

/* Connection callback used by the BLE layer to drive LED state. */
static void bleConnChanged(bool connected)
{
	if (connected) {
		/* Connected to the base: solid LED. */
		shearsLedSetSolidOn();
	} else {
		/* Not connected: blink while advertising. */
		shearsLedSetOff();
		shearsLedSetBlinking(true);
	}
}

/* --- Entry point ---------------------------------------------------------- */

void app_main(void)
{
	/* Initialize status LED and indicate idle/advertising state. */
	shearsLedInit();
	shearsLedSetBlinking(true);

	/* Start GPS logging subsystem. */
	shearsSpiffsInit();
	gpsLoggerInit();

	/* Start BLE peripheral mode and begin advertising. */
	shearsBleInit(bleConnChanged);

	/* Foreground remains idle; work is handled by background tasks. */
}

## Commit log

2025-11-13 Add clean ESP32 hub implementation without build artifacts
    [partitions.csv]
2025-11-14 Accomplished filtering/sorting functionality and pinning the coordinates on the map
2025-11-14 Integrate web UI with ESP32 hub - Add file serving handlers for HTML/CSS/JS/PNG - Connect frontend to /api/cuts endpoint - Add tooltip feature for map markers - Fix date format to MM/DD/YYYY - Auto-r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
2025-11-14 bring up BLE peripheral and connection status LED
2025-11-14 implement BLE scan/connect logic with GPIO33 status LED
2025-11-14 Fixed merge mess up
    [main.c]
2025-11-20 Broke down code into modules
    [base_led.c, main.c]
2025-11-20 Broke down shears code into modules
    [main.c, shears_led.c]
2025-11-20 Integrated gps_logger into shears firmware.
    [partitions.csv]
2025-12-01 Completed BLE file-transfer protocol (shears ↔ base) + full documentation overhaul
    [partitions.csv]
2025-12-02 Integrate Josh's BLE firmware with hub system
    - Added NimBLE support for BLE central functionality
    - Fixed all format specifier warnings (uint32_t -> %lu)
    - Adjusted partition table for larger binary (2MB app)
    - Integrated base_ble.c, log_transfer_client.c from Josh
    - Updated CMakeLists.txt with BLE source files
    - Created comprehensive README with setup/troubleshooting
    - Configured for 4MB flash at 115200 baud rate
    - Ready for testing with WM-SHEARS device
    [partitions.csv]
2026-01-27 Fixed shears_led.c missing code
    [shears_led.c]
2026-01-27 Modified print function to have line numbers and only print 5 most recent lines of gps_points.csv for debugging purposes.
2026-01-27 Updated baud rate and formatted the csv printing
2026-02-10 pwm for piezo
2026-02-10 double voltage for piezo, and fixing clear logic
    [gps_logger.c]
2026-02-12 Started The Stacking Interface BoardRTK in kiCad project, for version control I will be saving and iterating it in github for others to open and see as well
    [Stacking-Interface-BoardRTK.kicad_pcb, Stacking-Interface-BoardRTK.kicad_sch]
2026-02-16 Updates to schematic, now all include digital footprints
    [Stacking-Interface-BoardRTK.kicad_sch]
2026-02-16 Okay Have a PCB design still need to measure the actual pins to make sure it's 100% accurate and figure out the fill and such
    [ExtraJustInCaseStacking-Interface-BoardRTK.kicad_pcb, Stacking-Interface-BoardRTK.kicad_sch]
2026-02-16 Really trying to get the PCB okay... will have to work on it tmr
    [Stacking-Interface-BoardRTK.kicad_pcb]
2026-02-17 Pi base port, ESP handles BLE and UART TX to Pi, Pi hosts and serves web server, public api for data access and retrieval
    [partitions.csv]
2026-02-18 Fixed gps_points.csv not being sent correctly due to chunk size mismatch
    [csv_debug_button.c, main.c]
2026-02-18 UART from ESP32 defined and started. Need RPi to build and test reciever
2026-02-19 make spdt switch work!
2026-02-19 Updated Pi Base Code for UART RX, DB changes for updated packet
    [partitions.csv]
2026-02-23 Updated UART transfer pins
2026-02-25 Updated UART pins for base esp -> base rpi data transfer
    [gps_points_20260219_162531.csv, gps_points_20260219_162620.csv, gps_points_20260219_162621.csv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]
2026-03-03 Working on PCB, got the correct measurements for correct stacking with microcontroller elements
    [Stacking-Interface-BoardRTK.kicad_pcb]
2026-03-03 updating pcb
    [Stacking-Interface-BoardRTK.kicad_pcb, Stacking-Interface-BoardRTK.kicad_sch]
2026-03-03 pcb done
    [Stacking-Interface-BoardRTK.kicad_pcb, Stacking-Interface-BoardRTK.kicad_sch]
2026-03-05 fixing buggy trigger, now works
    [gps_logger.c]
2026-03-05 changed millsecond debounce
2026-03-05 finished designing pcb
    [Stacking-Interface-BoardRTK-B_Cu.gbr, Stacking-Interface-BoardRTK-B_Mask.gbr, Stacking-Interface-BoardRTK-B_Paste.gbr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]
2026-03-06 adding production files
    [watermelon_bom.csv, watermelon_designators.csv, watermelon_positions.csv]
2026-03-10 adding step files
    [Stacking-Interface-BoardRTK.kicad_pcb, pcb.step]
2026-03-10 Add manual cut create/delete and HDOP visualization modes
2026-03-12 feat: enhance cut management with manual input and HDOP support
    - Added a new section in the UI for manually adding cuts, including fields for latitude, longitude, HDOP, and UTC time.
    - Implemented functionality to handle HDOP values in the backend, allowing for more precise cut data.
    - Introduced a delete feature for selected cuts in the UI.
    - Updated styles for the new input panel and buttons.
    - Enhanced map rendering to reflect HDOP values in marker sizes and opacities.
2026-03-12 Updated base esp -> base rpi transfer to happen automatically rather than from a button press
2026-03-12 Remove deprecated base-data-fw and base-ble-fw directories
    [partitions.csv]
2026-03-12 Added quadruple beep when assert to csv fails
    [gps_logger.c]
2026-03-12 Fix insert_cut missing utc_date param.
    [database.py]
2026-03-12 Fix debug print table for 9-column CSV with utc_date
    [gps_logger.c, shears_piezo.c]
2026-03-12 Updated files to automatically transfer csv file if connected to bluetooth during a cut
2026-03-12 Adjust header detection in uart rx.py file.
2026-03-24 Fix status indicator, date filter, and manual cut date persistence
    [app.py, database.py, uart_receiver.py]
2026-03-24 Replace app.js with fixed version (status indicator, date filter, date persistence)
2026-03-24 Add auto network mode switching (hotspot vs AP) to boot scripts
2026-03-25 Add deleted cuts management feature with retention and recovery options
    - Introduced a new tab for managing deleted cuts, including a retention policy of 48 hours.
    - Implemented functions to fetch, display, and recover deleted cuts.
    - Enhanced UI with buttons for exporting CSV and recovering selected deleted cuts.
    - Updated styles for the new deleted cuts table and controls.
2026-03-30 pcb with components
2026-03-30 adding SolidWorks files
    [base.SLDASM, box.SLDPRT, box.STL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]
2026-03-31 Switch map accuracy to fix type and add manual fix quality input
    [app.py, database.py]
2026-03-31 offline leaflet functionality implemented
    [gps_points_20260326_140729.csv, gps_points_20260326_140739.csv, gps_points_20260326_143418.csv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]
2026-04-03 editing gpio pin for PCB
2026-04-14 clean repo
    [gps_points_20260326_140729.csv, gps_points_20260326_140739.csv, gps_points_20260326_143418.csv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]
